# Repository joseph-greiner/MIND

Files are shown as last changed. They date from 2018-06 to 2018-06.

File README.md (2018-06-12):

# MIND: Modular-IN2-Nixie-Display
This is a modular display made for Russian IN2 Nixie tubes. Each display contains 2 tubes and 2 LED decimal places. These can be stacked up as many as you would like, as long as the high voltage supply can provide the necessary current to run them.<br>

Version 1:<br>
  Basic disply functionality achieved. Yay!<br>
  An example of the current progress is at https://youtu.be/8mW3LZJ6aFY <br>
  <b>TODO:</b>
  <ul>
    <li>Add a current limiting circuit to the module, ideally no more than 2mA should be supplied to each tube.</li>
    <li>Change the connection header so that the boards can be stacked easier. Perhaps add a header to each side of the board.</li>
    <li>Change the shift register so that each module can shift the data out to the next, not sure what I was thinking.</li>
    <li>Decide on a better plan for the decimal places, the current one is cludgy and I don't like it.</li>
  </ul>

Each module is built up from one shift register and two BCD to decimal IC's and discrete components. The cost of each individual module was a high priority for me, so I have done my best to keep them under $5 US. Which achievable depending upon where your PCB's are made.

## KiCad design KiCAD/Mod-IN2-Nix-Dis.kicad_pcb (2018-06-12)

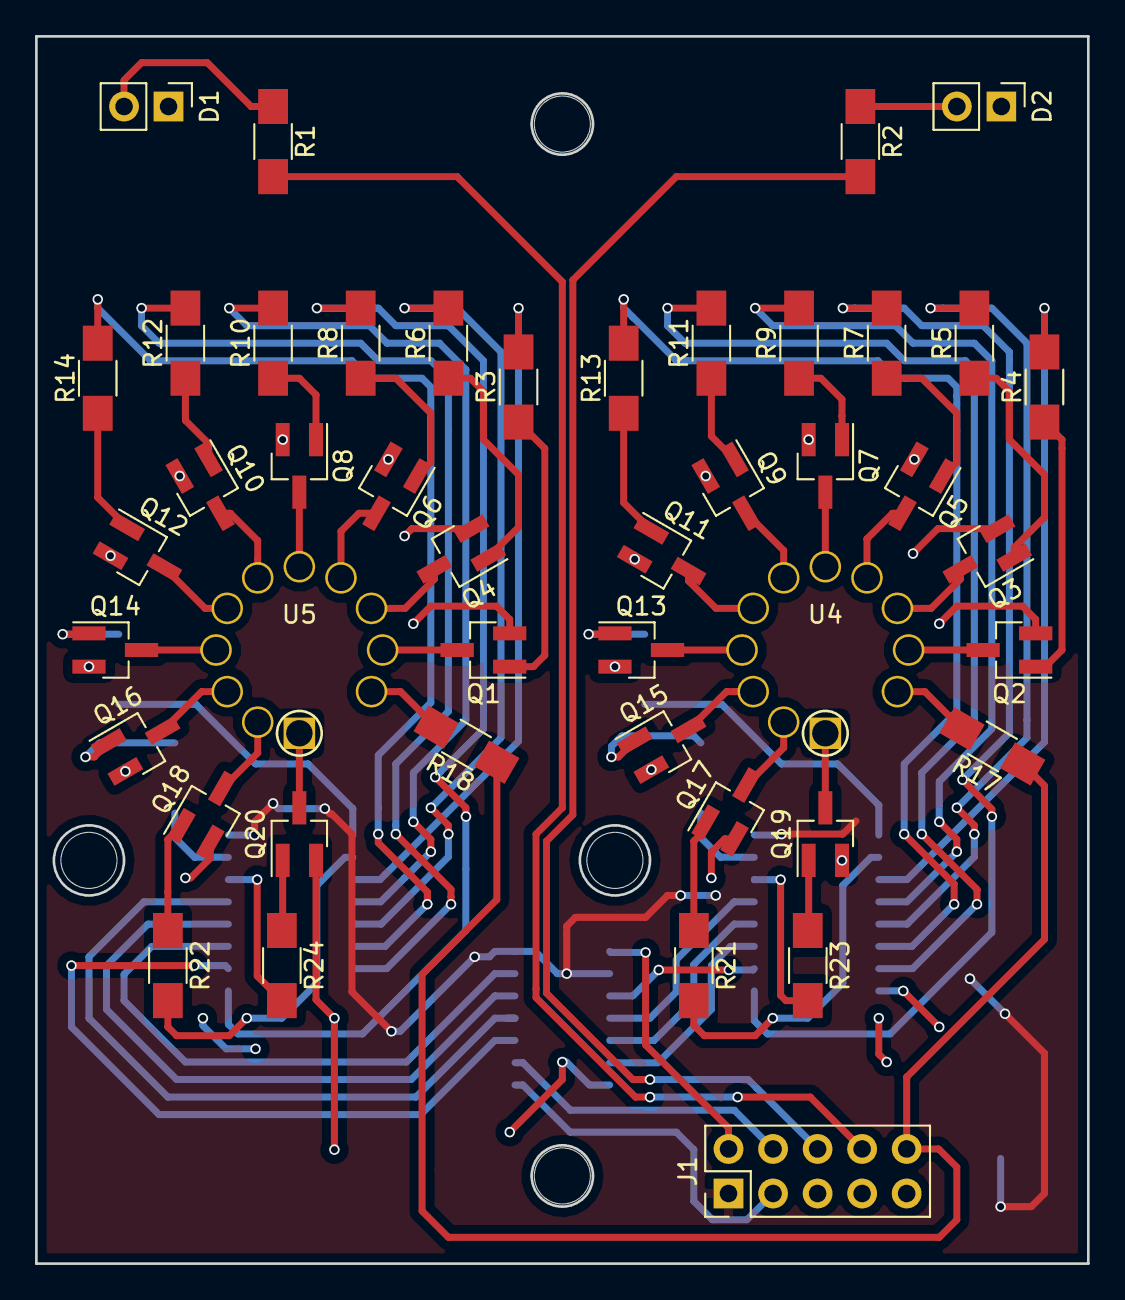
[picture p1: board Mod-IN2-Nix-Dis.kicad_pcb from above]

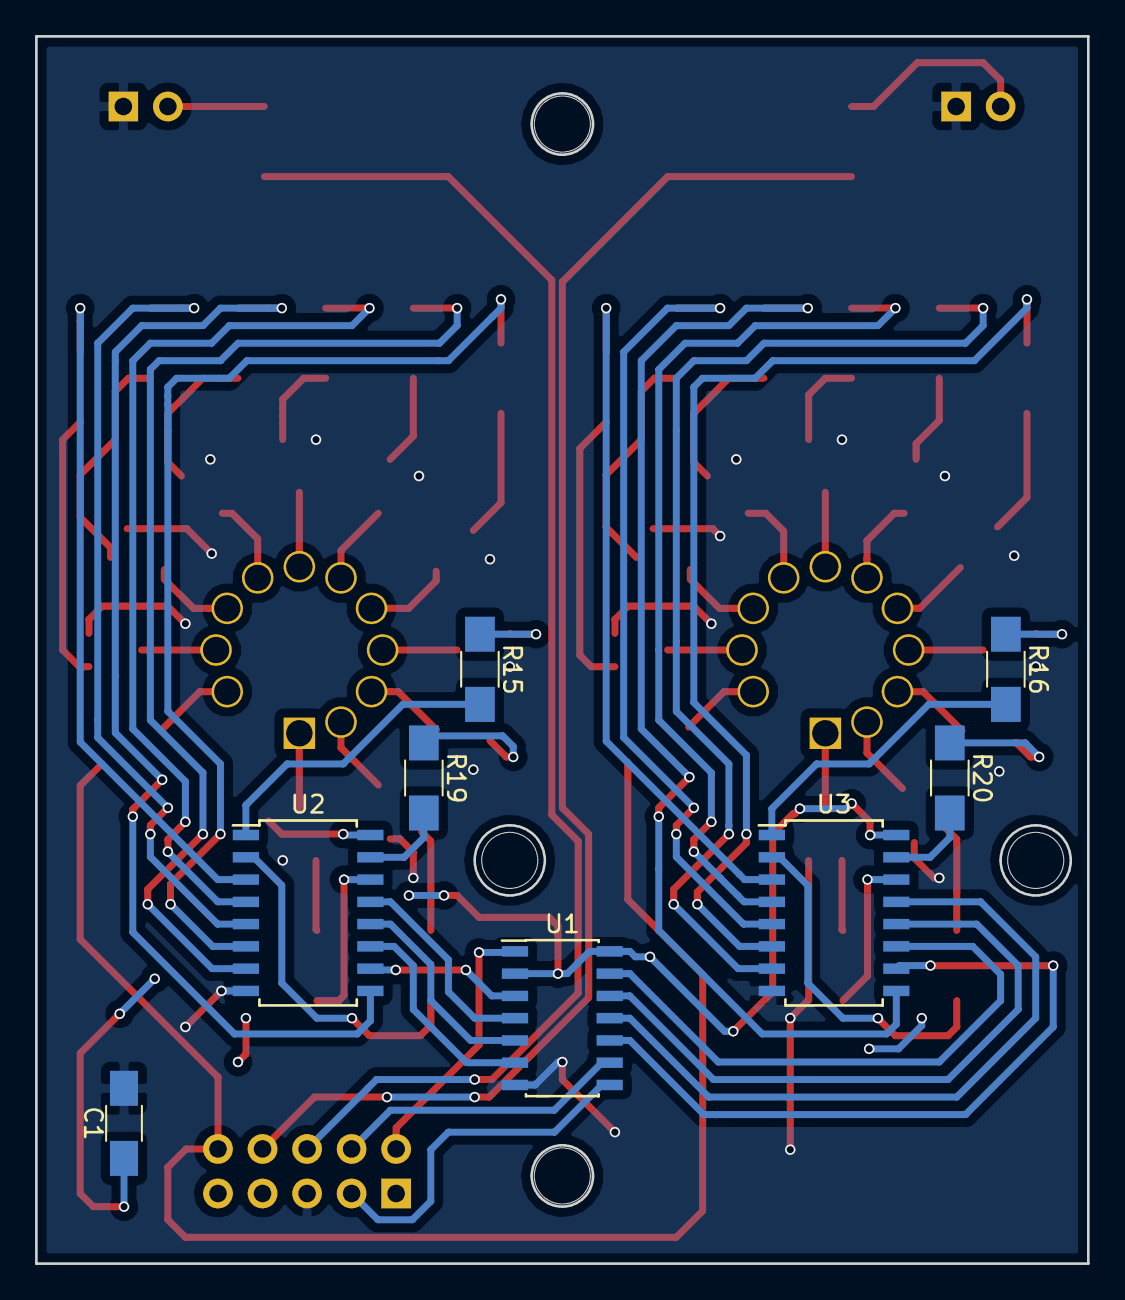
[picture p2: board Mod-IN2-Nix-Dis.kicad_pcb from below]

Board: 2 copper layers, 60.0 x 70.0 mm, 53 parts (8 on the bottom side), 80 nets.

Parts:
C1: 0.1uF; C_1206_HandSoldering
D1, D2: LED; Pin_Header_Straight_1x02_Pitch2.54mm
J1: Conn_02x05_Counter_Clockwise; Pin_Header_Straight_2x05_Pitch2.54mm
Q1, Q2, Q3, Q4, Q5, Q6, Q7, Q8, Q9, Q10, Q11, Q12, Q13, Q14, Q15, Q16, Q17, Q18, Q19, Q20: MMBTA42L; SOT-23_Handsoldering
R1, R2: 200; R_1206_HandSoldering
R3, R4, R5, R6, R7, R8, R9, R10, R11, R12, R13, R14, R15, R16, R19, R20, R21, R22, R23, R24: 15k; R_1206_HandSoldering
R17, R18: 22k; R_1206_HandSoldering
U1: 74HC164; SOIC-14_3.9x8.7mm_Pitch1.27mm
U2, U3: 4028; SOIC-16W_5.3x10.2mm_Pitch1.27mm
U4, U5: IN-2; Nixie-IN2

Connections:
+5V: C1.1, J1.1, U1.2, U1.14, U2.16, U3.16
+170VDC: J1.10, R17.1, R18.1
CLK: J1.3, U1.8
DATA: J1.2, U1.1
DIG_1_DEC: J1.8, R1.2
DIG_2_DEC: J1.6, R2.2
GND: C1.2, D1.1, D2.1, J1.5, Q1.2, Q2.2, Q3.2, Q4.2, Q5.2, Q6.2, Q7.2, Q8.2, Q9.2, Q10.2, Q11.2, Q12.2, Q13.2, Q14.2, Q15.2, Q16.2, Q17.2, Q18.2, Q19.2, Q20.2, U1.7, U2.8, U3.8
unnamed: D1.2, R1.1
unnamed: D2.2, R2.1
unnamed: Q1.1, R3.1
unnamed: Q1.3, U5.10
unnamed: Q2.1, R4.1
unnamed: Q2.3, U4.10
unnamed: Q3.1, R5.1
unnamed: Q3.3, U4.9
unnamed: Q4.1, R6.1
unnamed: Q4.3, U5.9
unnamed: Q5.1, R7.1
unnamed: Q5.3, U4.8
unnamed: Q6.1, R8.1
unnamed: Q6.3, U5.8
unnamed: Q7.1, R9.1
unnamed: Q7.3, U4.7
unnamed: Q8.1, R10.1
unnamed: Q8.3, U5.7
unnamed: Q9.1, R11.1
unnamed: Q9.3, U4.6
unnamed: Q10.1, R12.1
unnamed: Q10.3, U5.6
unnamed: Q11.1, R13.1
unnamed: Q11.3, U4.5
unnamed: Q12.1, R14.1
unnamed: Q12.3, U5.5
unnamed: Q13.1, R15.1
unnamed: Q13.3, U4.4
unnamed: Q14.1, R16.1
unnamed: Q14.3, U5.4
unnamed: Q15.1, R19.1
unnamed: Q15.3, U4.3
unnamed: Q16.1, R20.1
unnamed: Q16.3, U5.3
unnamed: Q17.1, R21.1
unnamed: Q17.3, U4.2
unnamed: Q18.1, R22.1
unnamed: Q18.3, U5.2
unnamed: Q19.1, R23.1
unnamed: Q19.3, U4.1
unnamed: Q20.1, R24.1
unnamed: Q20.3, U5.1
unnamed: R3.2, U3.3
unnamed: R4.2, U2.3
unnamed: R5.2, U2.5
unnamed: R6.2, U3.5
unnamed: R7.2, U2.9
unnamed: R8.2, U3.9
unnamed: R9.2, U2.4
unnamed: R10.2, U3.4
unnamed: R11.2, U2.7
unnamed: R12.2, U3.7
unnamed: R13.2, U2.6
unnamed: R14.2, U3.6
unnamed: R15.2, U2.1
unnamed: R16.2, U3.1
unnamed: R17.2, U4.11
unnamed: R18.2, U5.11
unnamed: R19.2, U2.15
unnamed: R20.2, U3.15
unnamed: R21.2, U2.2
unnamed: R22.2, U3.2
unnamed: R23.2, U2.14
unnamed: R24.2, U3.14
unnamed: U1.3, U2.10
unnamed: U1.4, U2.13
unnamed: U1.5, U2.12
unnamed: U1.6, U2.11
unnamed: U1.10, U3.10
unnamed: U1.11, U3.13
unnamed: U1.12, U3.12
unnamed: U1.13, U3.11
~CLR: J1.4, U1.9

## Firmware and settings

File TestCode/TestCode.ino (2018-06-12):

/* Test Code for Modular IN2 Nixie Display.
 * 
 * Revision 0.1 19 April 2018
 */

unsigned long ul_Count = 0;

const byte clkPin = 2;
const byte clrPin = 3;
const byte datPin = 4;

void setup() {
  Serial.begin(9600);
  pinMode(clkPin, OUTPUT);
  pinMode(clrPin, OUTPUT);
  pinMode(datPin, OUTPUT);

  digitalWrite(clkPin, LOW);
  digitalWrite(clrPin, HIGH); // Clear is active low, so set to high for now.
  digitalWrite(datPin, LOW);
}

void loop() {
  digitalWrite(datPin, LOW);  // Start with the data pin low
  /*while(Serial.available()>0){
    ul_Count = long(Serial.parseInt());
    //Serial.println();
    processOutput(ul_Count);
    if(Serial.read() == '\n'){
      Serial.println("");
    }
  }*/
  for(int i = 0; i<=99; i++)
  {
    delay(250);
    processOutput(i);
    delay(250);
  }
}

void processOutput(unsigned long ulTest){
  int x = 0;
  
  do{
      byte bDisplay[4] = {0, 0, 0, 0};  // Array to hold the 4 bytes that will be shifted out.
      byte bHabyte[2] = {0, 0};         // Array to hold 2 digits before being placed into the display array.
      Serial.println(ulTest);           // Feedback to the serial monitor the data that should be displayed on the tubes.
      // Grab the 2 least significant digits, and put them into the array.
      for(int i=0;i<2;i++){
        bHabyte[i] = ulTest % 10;       // Set the first half byte to the LSD of the number.
        ulTest = ulTest / 10;           // Trim off the LSD.
        if(i==0){
          bHabyte[i] = bHabyte[i] << 4; // Shift the bits over by 4 
        }
        if(i==1){
          bDisplay[x] = bHabyte[i] | bHabyte[i-1]; // OR the bytes together.
        }
      }
      Serial.println(bDisplay[x], BIN); // Display the byte we are shifting out in binary
      digitalWrite(clkPin, LOW);        // Ensure the clock pin is low
      shiftOut(datPin, clkPin, MSBFIRST, bDisplay[x]);
      x++;
    }while(ulTest > 0);
}
